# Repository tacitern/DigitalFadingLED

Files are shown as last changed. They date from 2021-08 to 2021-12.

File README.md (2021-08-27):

# DigitalFadingLED
Microcontroller project which uses a usb virtual serial port to control a RGB LEDs color, brightness and fade rate

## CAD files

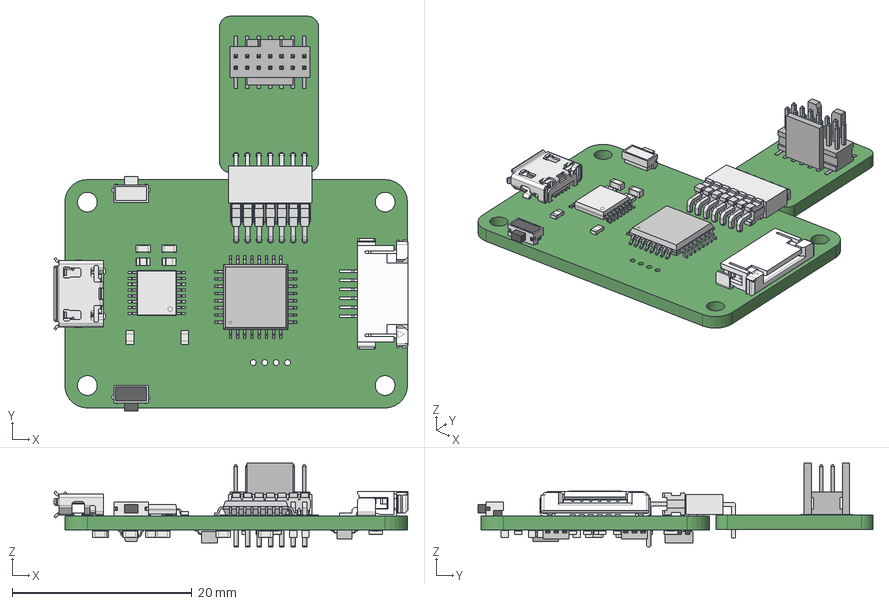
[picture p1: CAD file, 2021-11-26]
hardware/DigitalBoardandProgrammingBoard.FCStd
39.4 x 43.9 x 9.33 mm

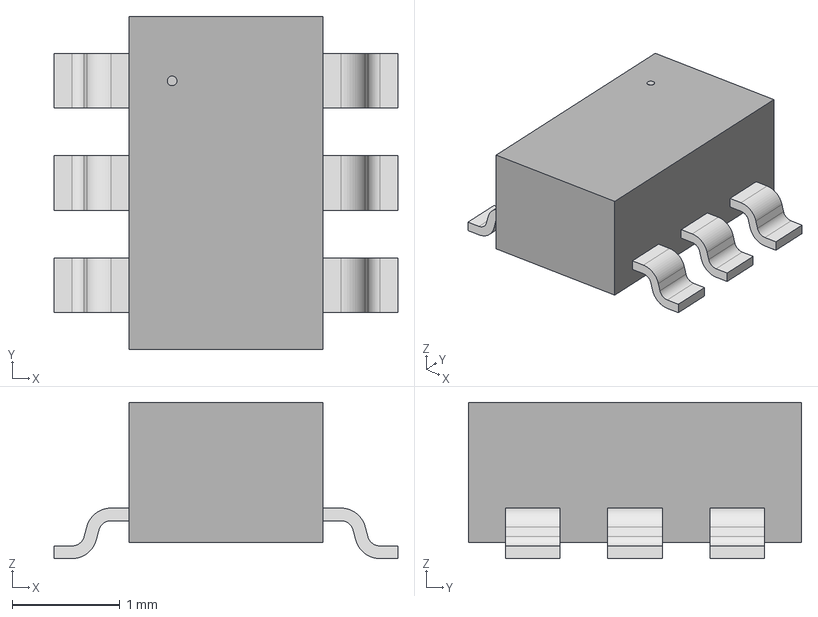
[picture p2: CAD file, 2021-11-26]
hardware/DigitalFadingLED/footprints/34AA02_EEPROM/SOT-23-6_MC_MCH.step
3.20 x 3.10 x 1.45 mm

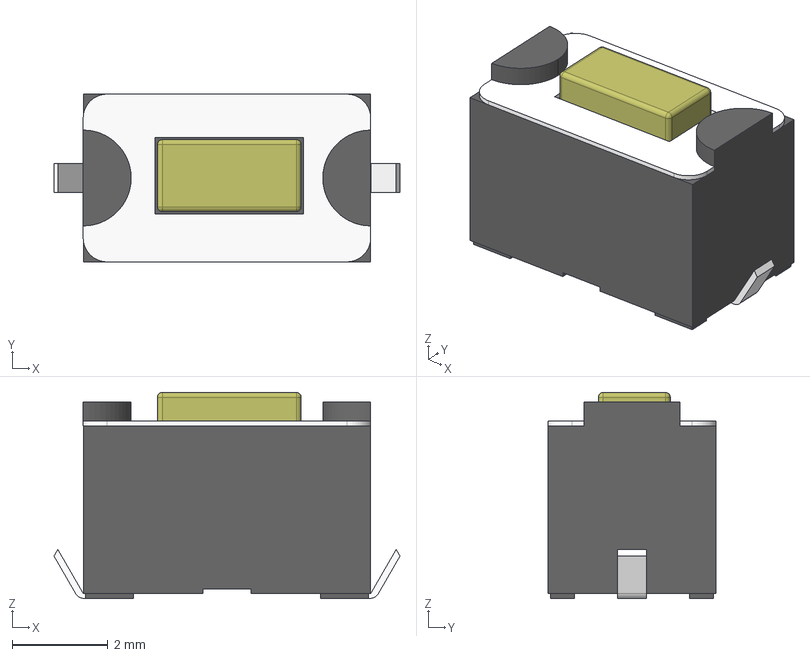
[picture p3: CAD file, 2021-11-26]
hardware/DigitalFadingLED/footprints/95C04A3GWRT_Button/95C04A3GWRT.step
7.22 x 3.50 x 4.30 mm

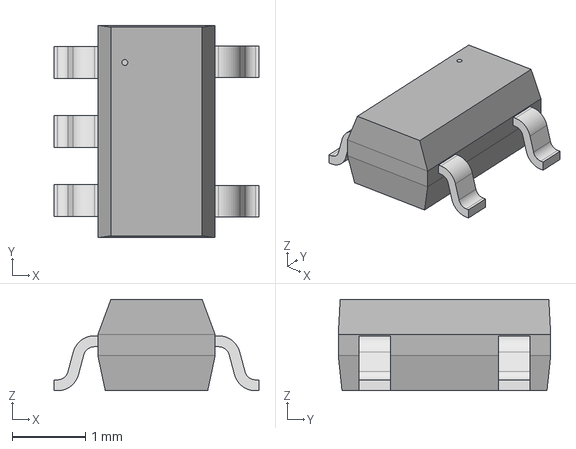
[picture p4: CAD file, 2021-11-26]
hardware/DigitalFadingLED/footprints/BU33SD5WG-TR_3V3_REG/SSOP5_ROM.step
2.79 x 2.90 x 1.25 mm

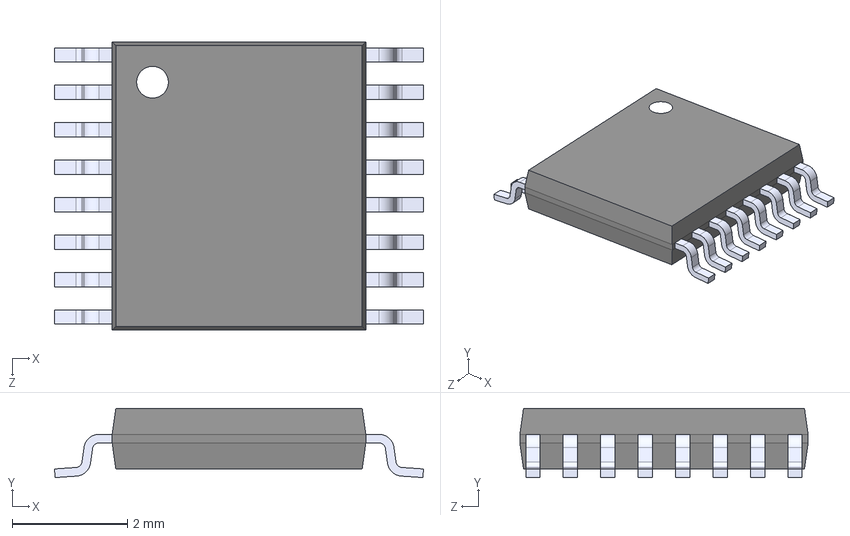
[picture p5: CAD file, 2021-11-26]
hardware/DigitalFadingLED/footprints/FT230XS/FX230.step
6.40 x 1.20 x 5.00 mm

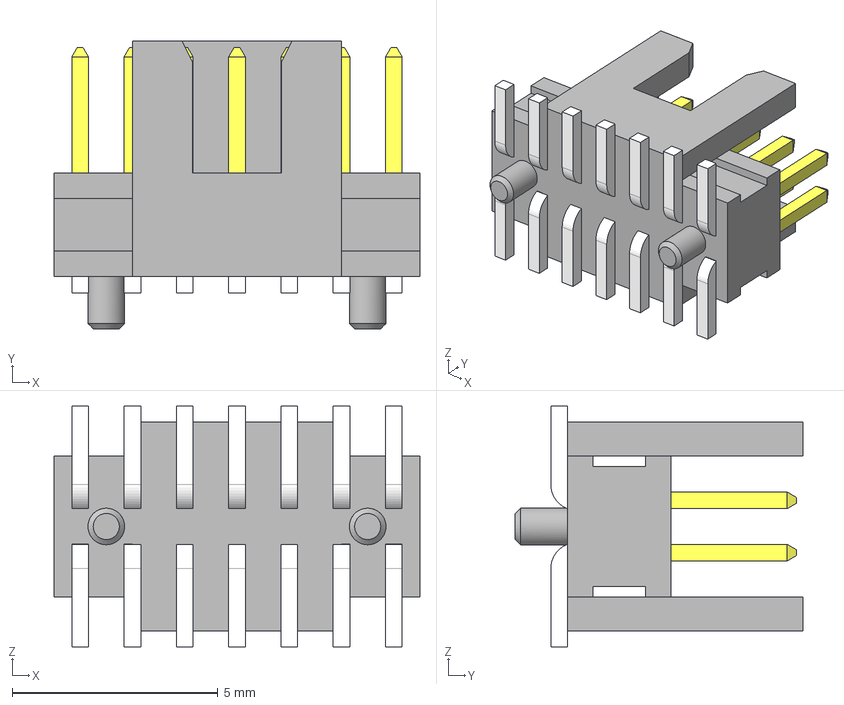
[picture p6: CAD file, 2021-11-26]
hardware/DigitalFadingLED/footprints/FTSH-107-01-L-DV-K-A_ProgrammingHeader/FTSH-107-01-L-DV-K-A.stp
8.89 x 6.98 x 5.84 mm
_FTSH-107-01-L-DV-K-A_body
_FTSH-107-01-L-DV-K-A_pins1
_FTSH-107-01-L-DV-K-A_pins2

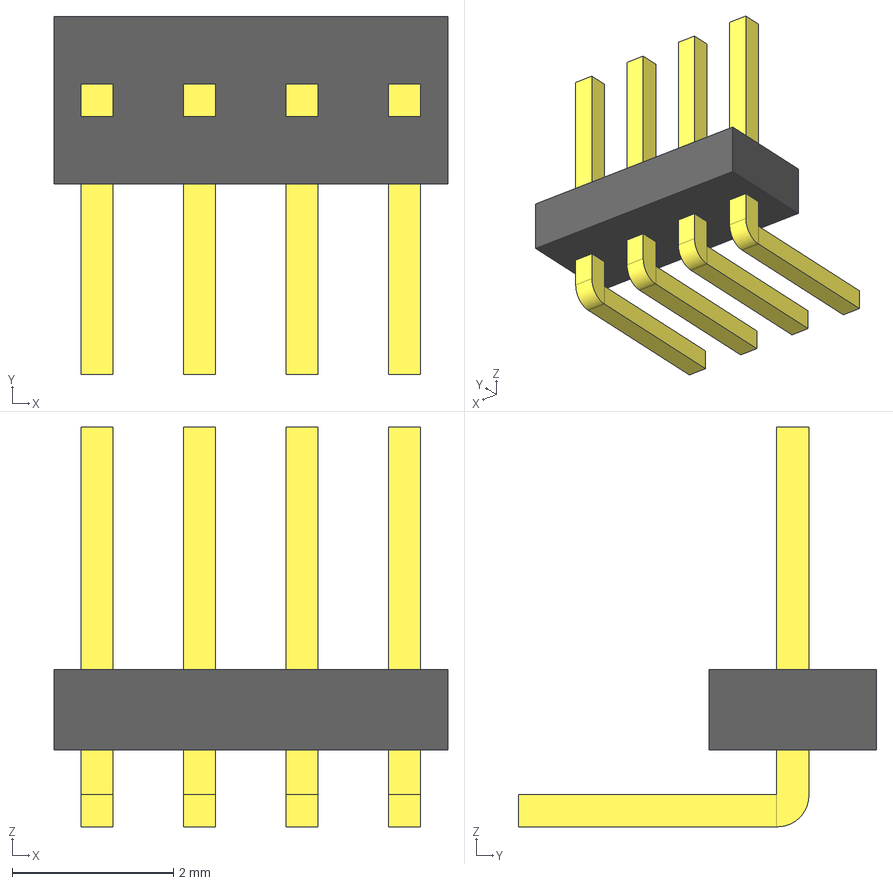
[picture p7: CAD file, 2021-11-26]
hardware/DigitalFadingLED/footprints/GRPB041VWCN-RC_4pos_PinHeader/GRPB041VWCN-RC.step
4.88 x 4.44 x 4.95 mm

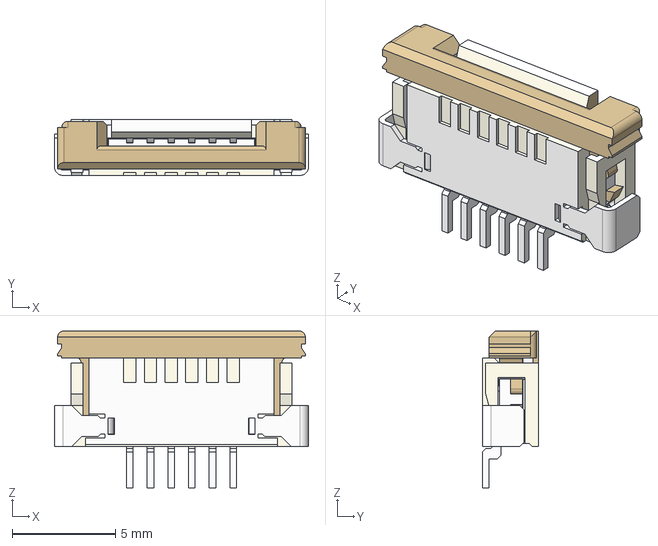
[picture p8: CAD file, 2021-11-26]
hardware/DigitalFadingLED/footprints/Molex_FFC/Molex_FFC_0522070633.step
12.3 x 2.70 x 7.60 mm

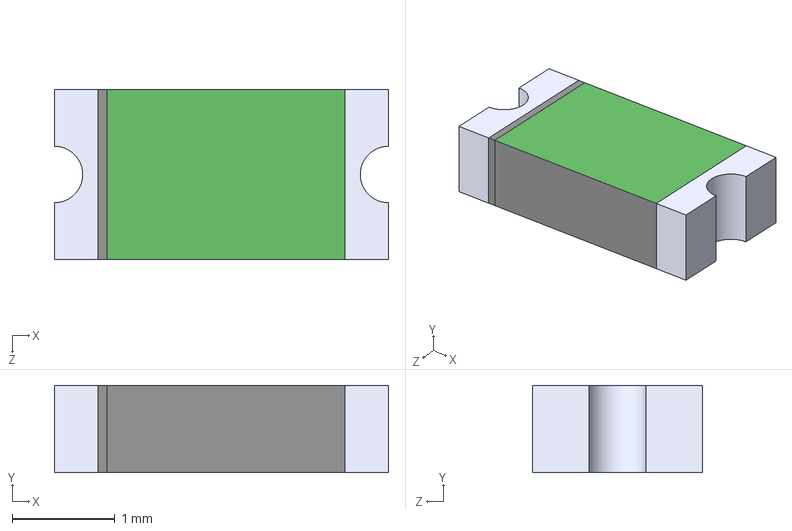
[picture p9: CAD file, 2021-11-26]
hardware/DigitalFadingLED/footprints/PTC_0ZCJ0020FF2E.STEP
3.25 x 0.85 x 1.65 mm

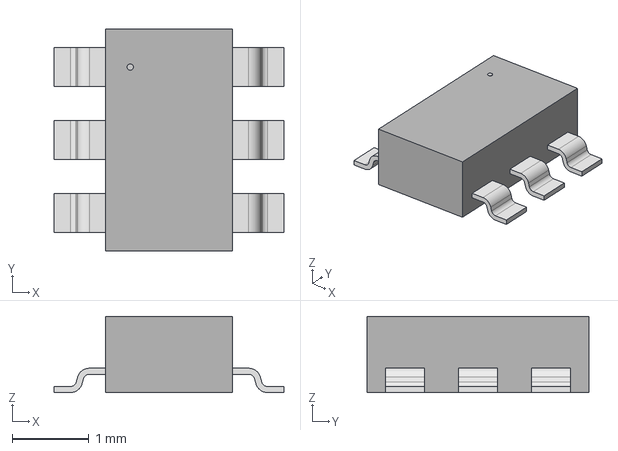
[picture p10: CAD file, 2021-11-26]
hardware/DigitalFadingLED/footprints/QS6K21_2-N-CH/TRANS_QS6_ROM.step
3.00 x 2.90 x 0.993 mm

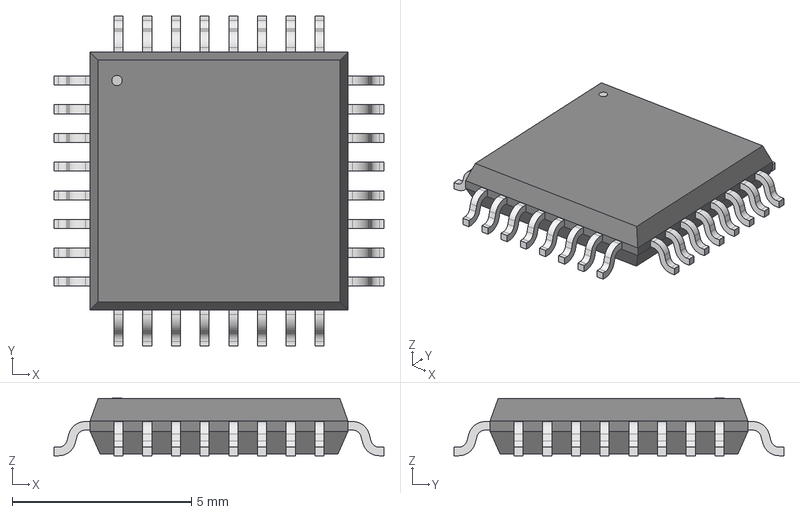
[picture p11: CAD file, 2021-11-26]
hardware/DigitalFadingLED/footprints/STM32L071KZT6/LQFP32_7X7X1P4.step
9.19 x 9.19 x 1.60 mm

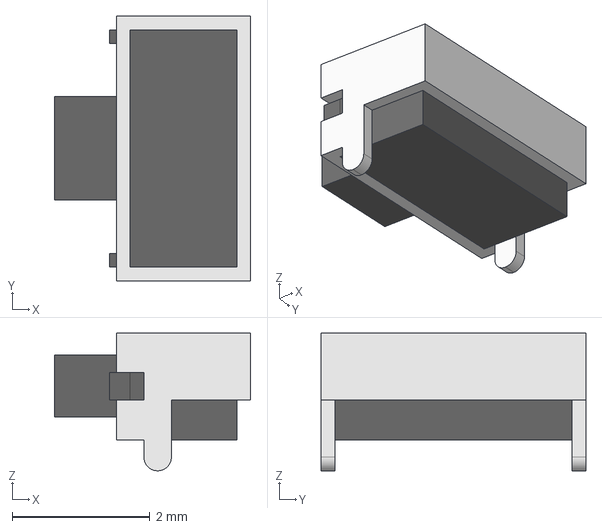
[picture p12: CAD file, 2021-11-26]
hardware/DigitalFadingLED/footprints/TL6340AF160Q_Button/TL6340AF160Q.step
2.85 x 3.85 x 2.00 mm

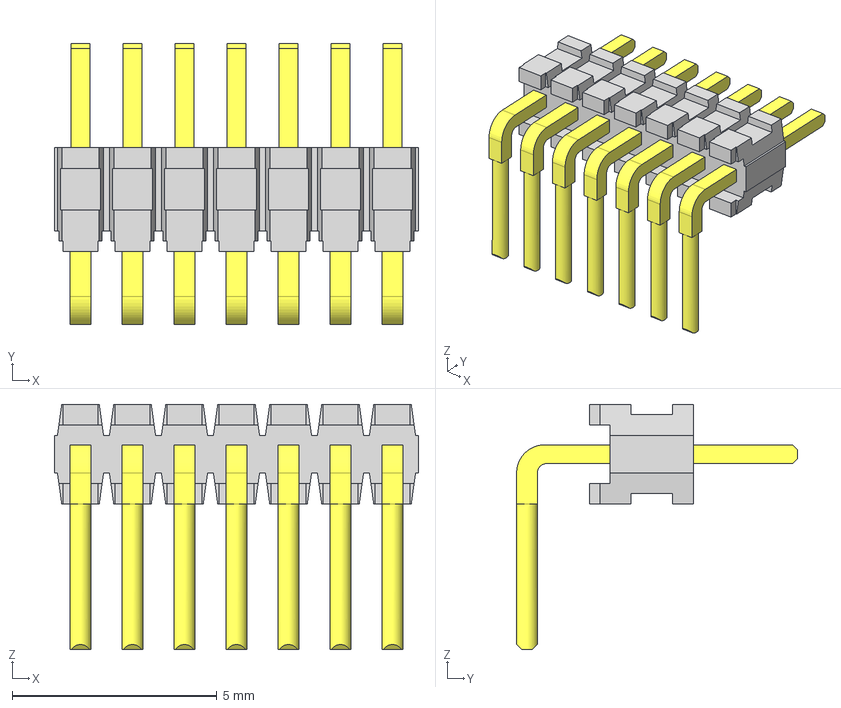
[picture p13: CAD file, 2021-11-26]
hardware/DigitalFadingLED/footprints/TMS-107-02-G-S-RA_7pos_PinHeader/TMS-107-02-G-S-RA.stp
8.89 x 6.86 x 5.99 mm
_TMS-107-S_header
_T-1M6-07-02-S-RA

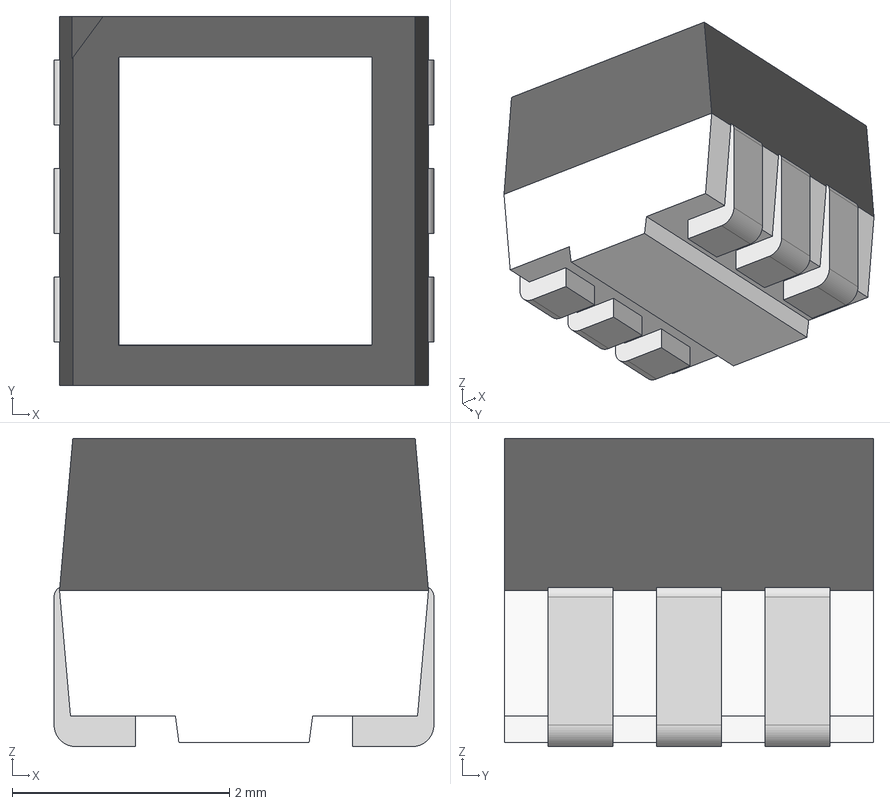
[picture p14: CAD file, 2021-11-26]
hardware/LedBoard/footprints/6-PLCC.STEP
3.50 x 3.40 x 2.84 mm

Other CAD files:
hardware/DigitalFadingLED/footprints/QS6M4_N-CH_P-CH/TRANS_QS6_ROM.step
hardware/LedBoard/LedBoard.step
hardware/DigitalFadingLED/footprints/95C04A3GWRT_Button/95C04A3GWRT.FCStd
hardware/DigitalFadingLED/footprints/FT230XS/FX230XS.FCStd
hardware/DigitalFadingLED/footprints/GRPB041VWCN-RC_4pos_PinHeader/GRPB041VWCN-RC.FCStd
hardware/DigitalFadingLED/footprints/Micro_USB_10118194-0001LF/10118194-0001LF.step
hardware/DigitalFadingLED/footprints/TL6340AF160Q_Button/TL6340AF160Q.FCStd
hardware/LedBoard/footprints/PLCC6.FCStd
hardware/ProgrammingAdapterBoard/ProgrammingAdapterBoard.step
hardware/ProgrammingAdapterBoard/footprints/Preci-Dip_851-87-007-20-001101_7pos_Soccket/851-87-007-20-001101.FCStd
hardware/ProgrammingAdapterBoard/footprints/Preci-Dip_851-87-007-20-001101_7pos_Soccket/851-87-007-20-001101.step

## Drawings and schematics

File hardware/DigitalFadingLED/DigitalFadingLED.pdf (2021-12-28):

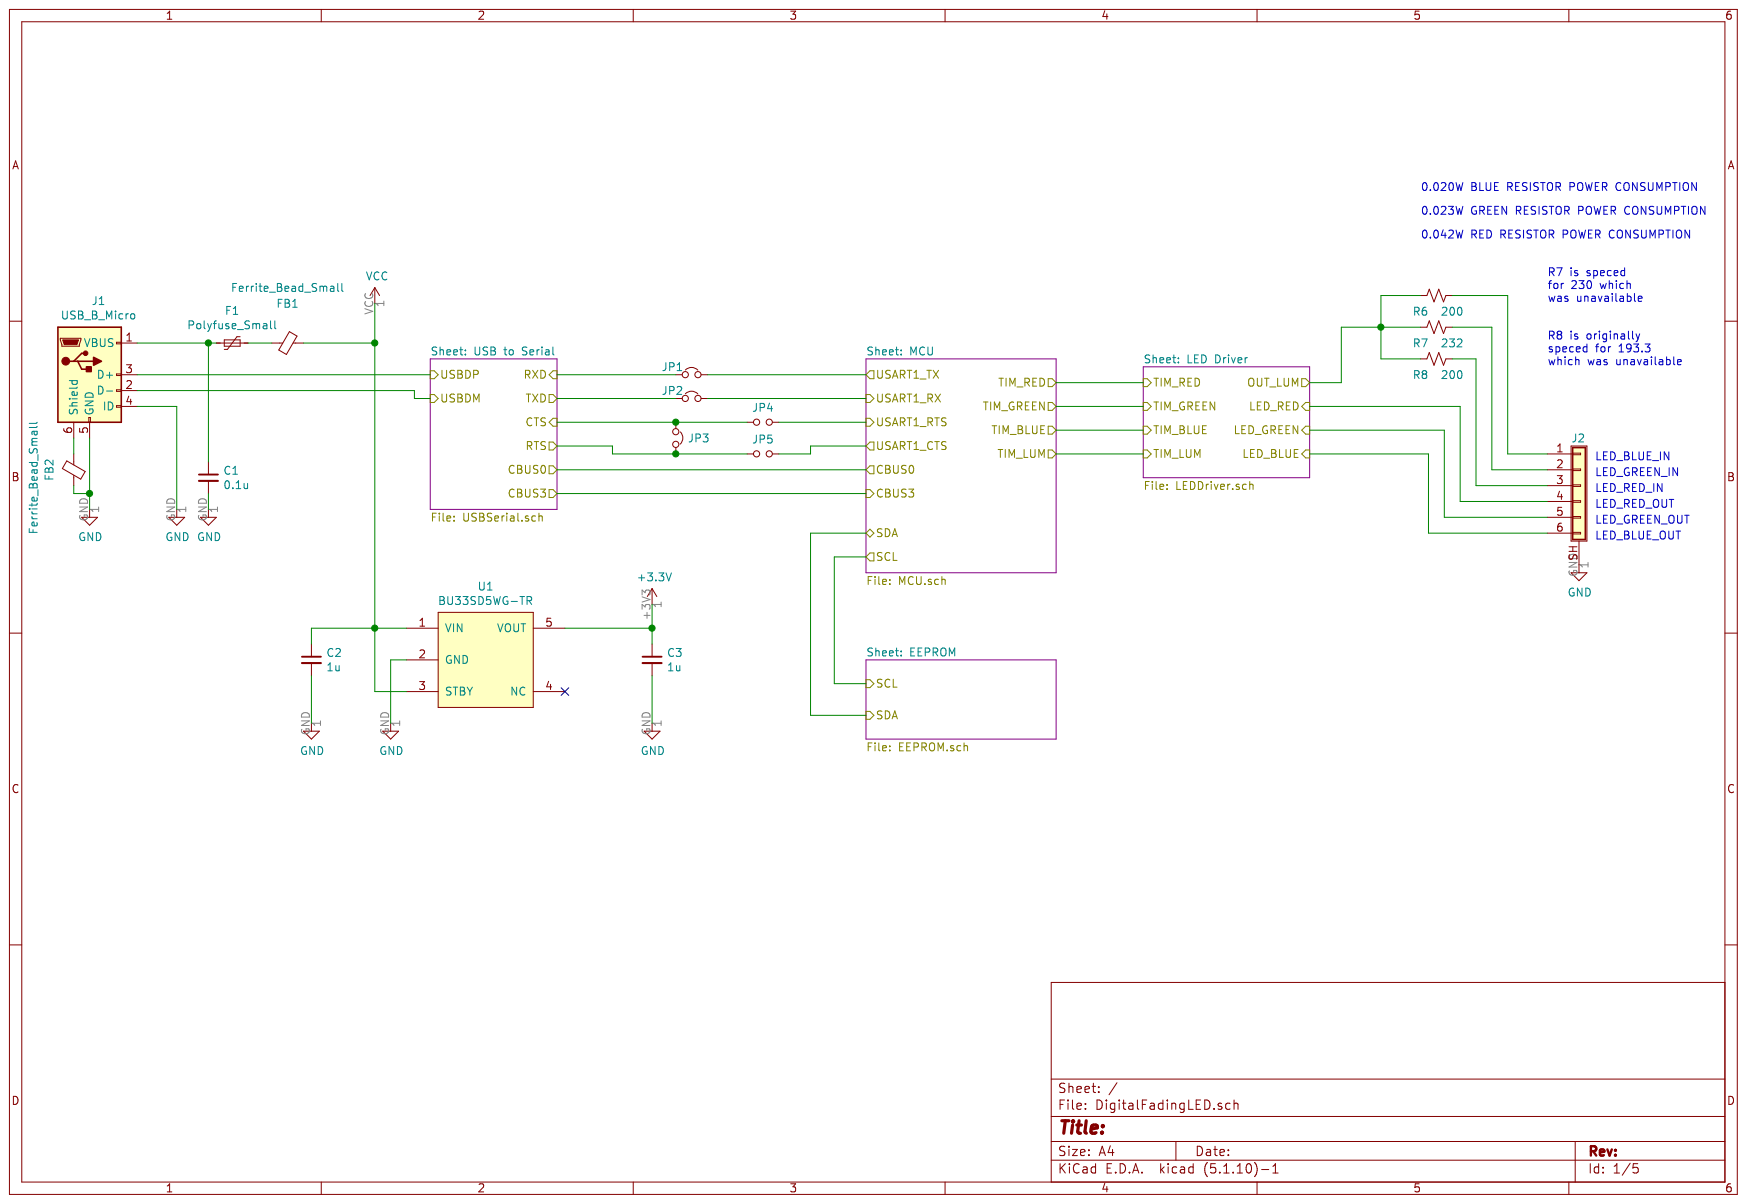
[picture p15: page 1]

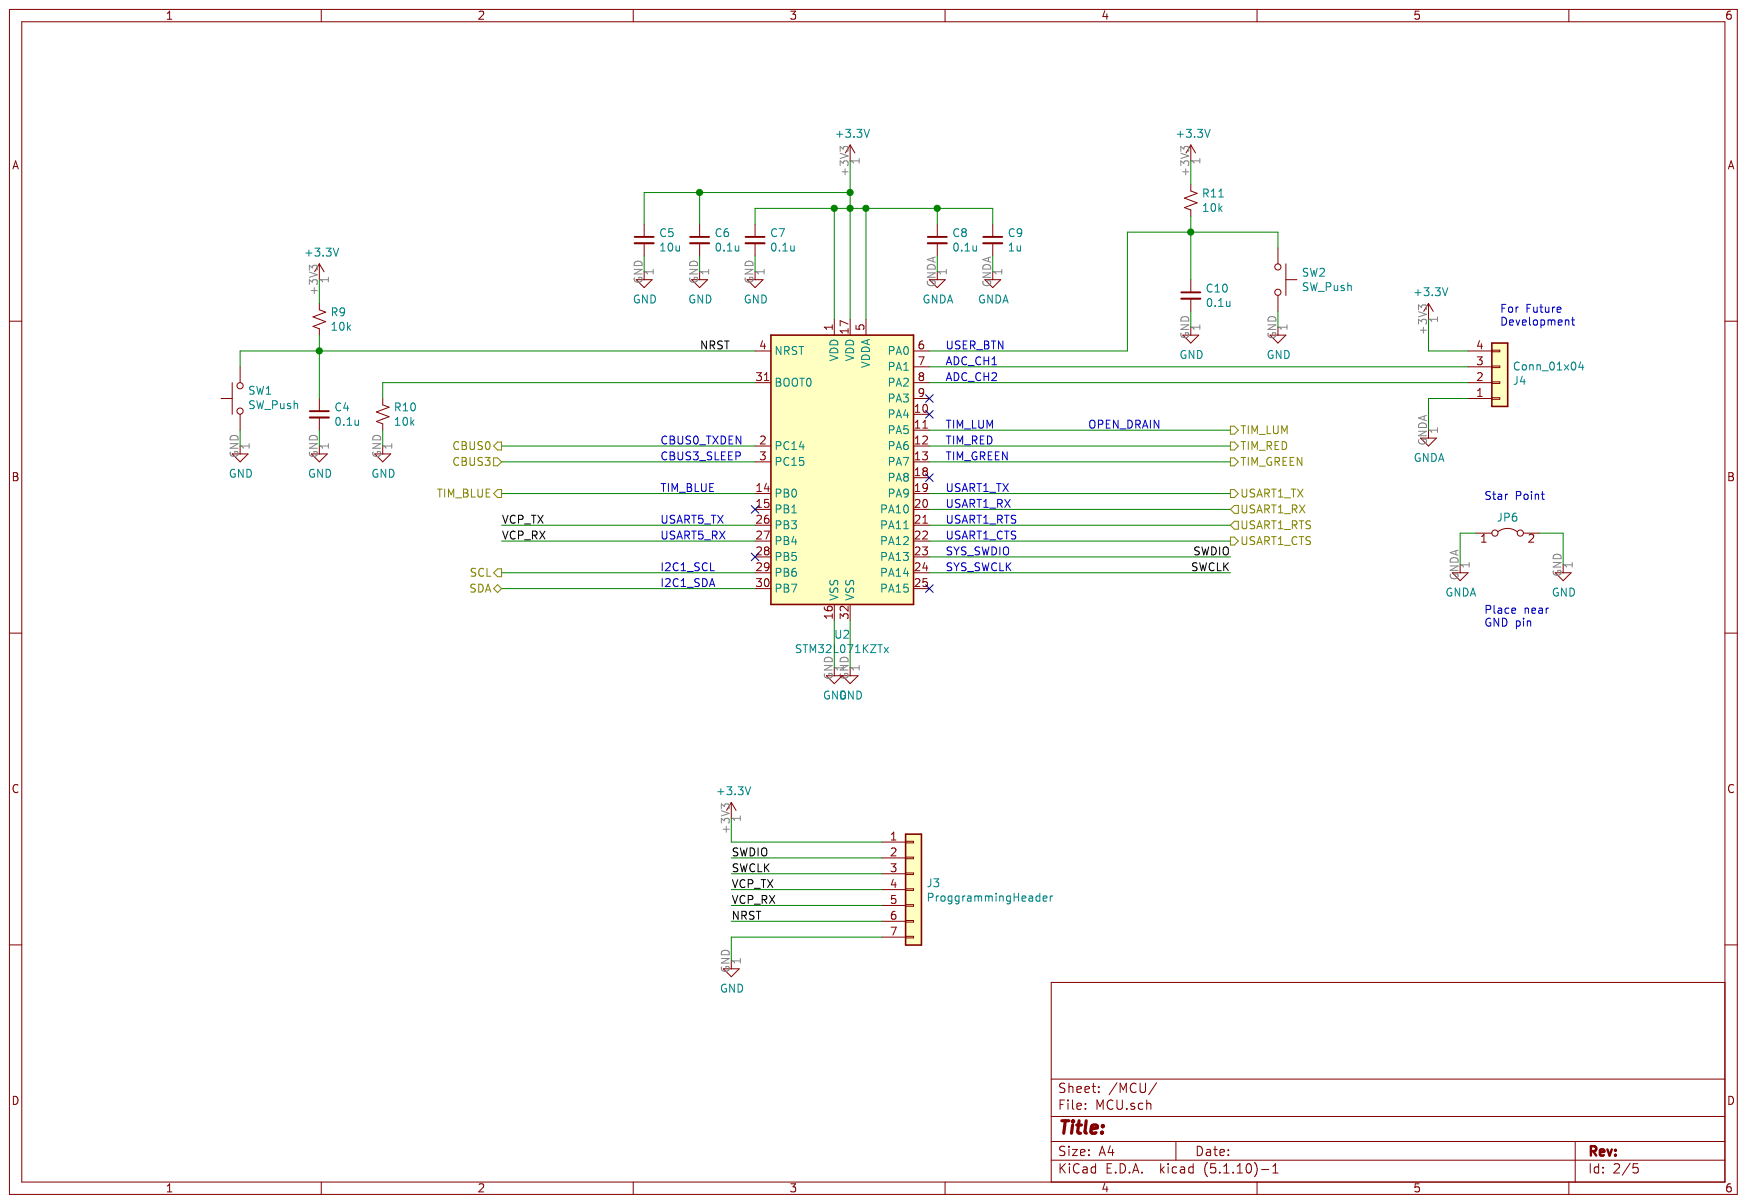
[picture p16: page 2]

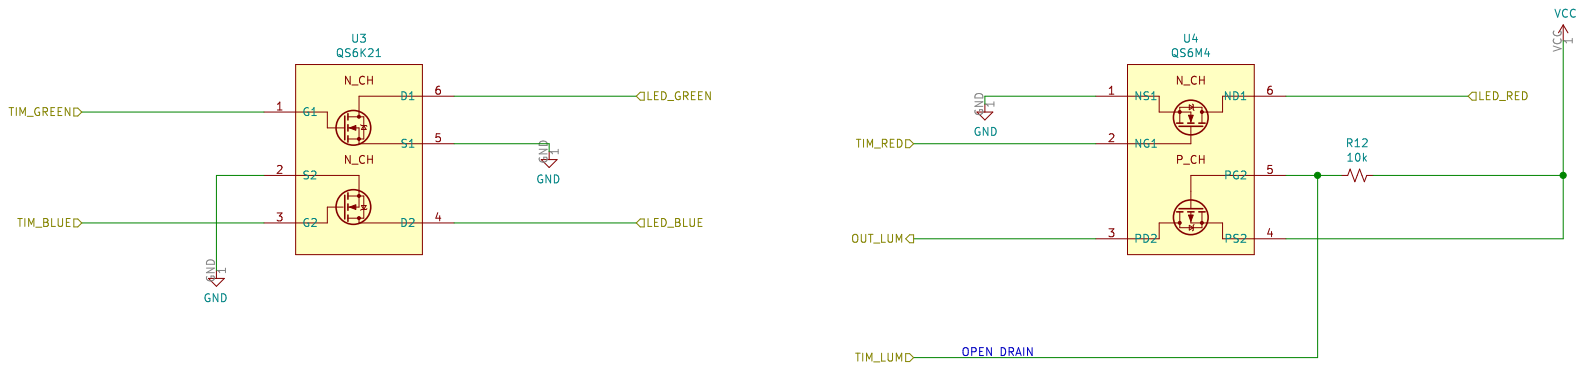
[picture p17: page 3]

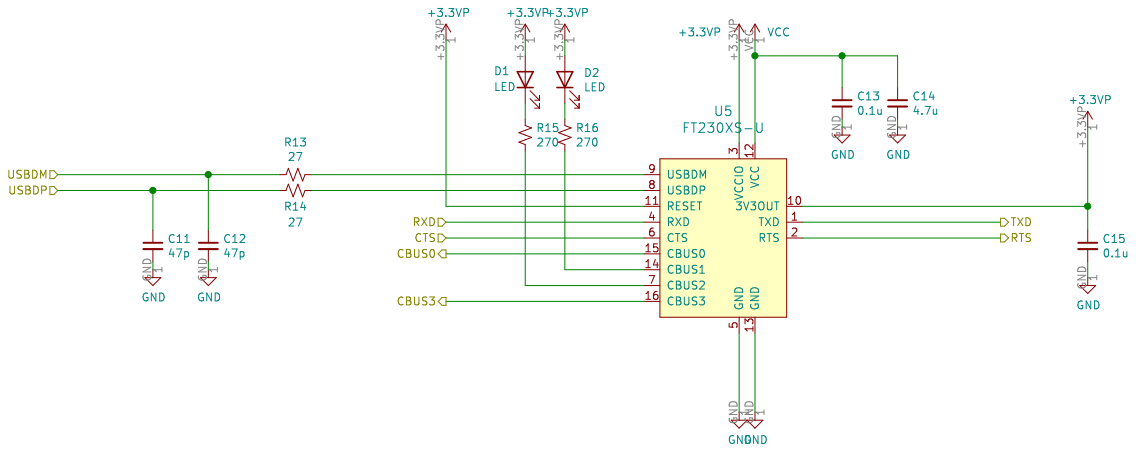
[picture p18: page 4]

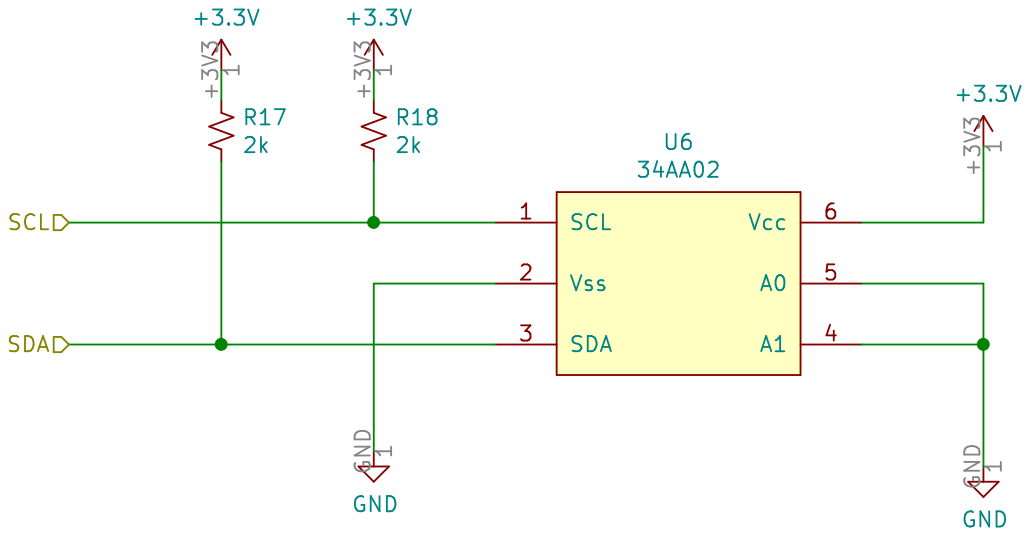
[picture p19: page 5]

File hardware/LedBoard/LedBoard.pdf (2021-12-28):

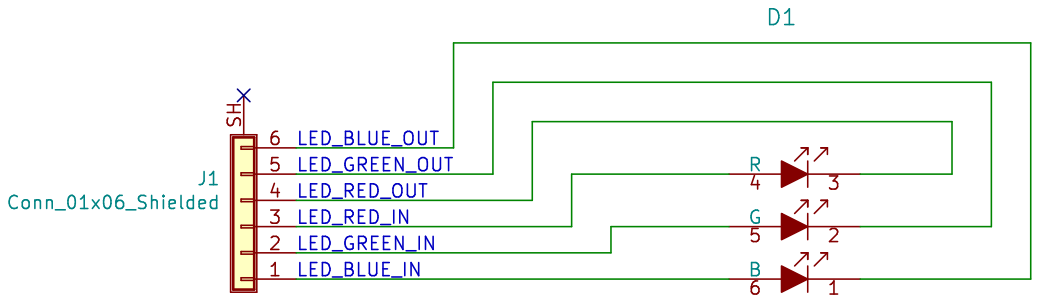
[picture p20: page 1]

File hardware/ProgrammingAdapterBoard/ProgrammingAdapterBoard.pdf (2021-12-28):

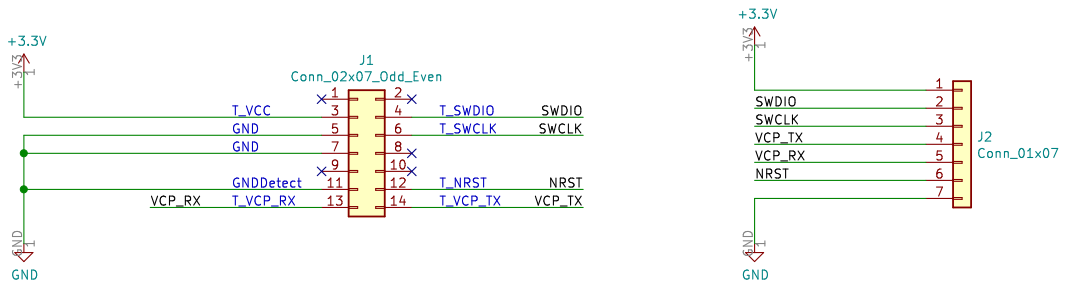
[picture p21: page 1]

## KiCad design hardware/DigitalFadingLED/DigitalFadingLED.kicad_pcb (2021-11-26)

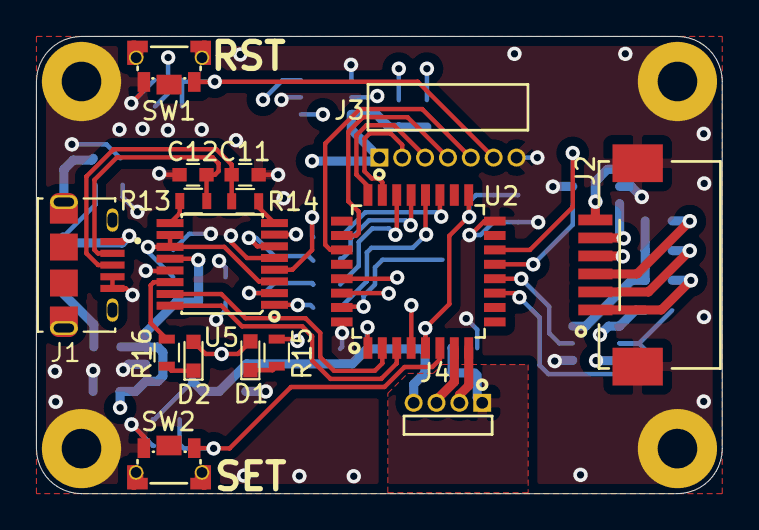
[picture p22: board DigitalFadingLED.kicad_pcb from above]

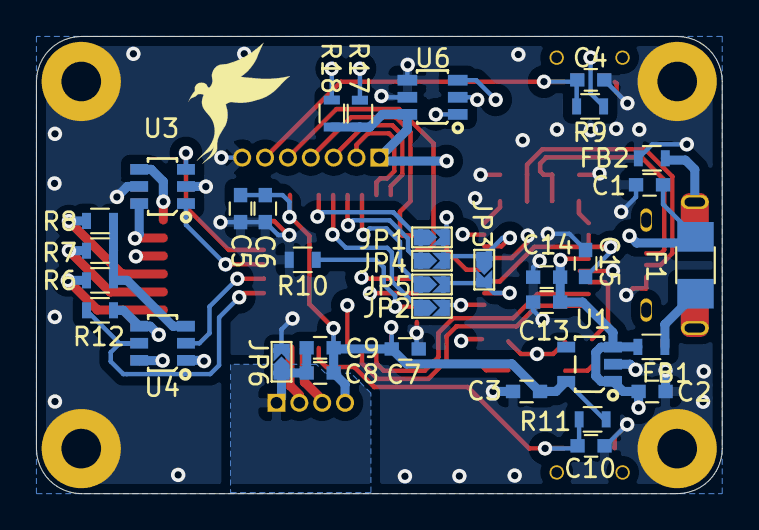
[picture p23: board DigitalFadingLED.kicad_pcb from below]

Board: 4 copper layers, 38.1 x 25.4 mm, 51 parts (35 on the bottom side), 47 nets.

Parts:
C1, C4, C6, C7, C8, C10, C13, C15: 0.1u; C_0603
C2, C3, C9: 1u; C_0603
C5: 10u; C_0603
C11, C12: 47p; C_0603
C14: 4.7u; C_0603
D1, D2: LED; LED_0603
F1: Polyfuse_Small; Fuse_SMD1206_Wave
FB1, FB2: Ferrite_Bead_Small; R_0603
J1: USB_B_Micro; AMPHENOL_10118194-0001LF
J2: molex_FFC_0522070633
J3: Conn_01x07; TMS-107-02-G-S-RA
J4: Conn_01x04; GRPB041VWCN-RC
JP1, JP2, JP3, JP4, JP5, JP6: jump
R6, R8: 200; R_0603
R7: 232; R_0603
R9, R10, R11, R12: 10k; R_0603
R13, R14: 27; R_0603
R15, R16: 270; R_0603
R17, R18: 2k; R_0603
SW1, SW2: SW_Push; TL6340AF160Q
U1: BU33SD5WG-TR; BU33SD5WG
U2: STM32L071KZTx; STM32L071KZT6
U3: QS6K21; QS6K21TR
U4: QS6M4; QS6K21TR
U5: FT230XS-U; FT230XS
U6: 34AA02

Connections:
+3.3VP: C15.1, D1.2, D2.2, U5.3, U5.10, U5.11
+3V3: C3.1, C5.1, C6.1, C7.1, C8.1, C9.1, J3.1, J4.4, R9.1, R11.1, R17.1, R18.1, U1.5, U2.1, U2.5, U2.17, U6.6
/EEPROM/SCL: R18.2, U2.29, U6.1
/EEPROM/SDA: R17.2, U2.30, U6.3
/LED Driver/LED_BLUE: J2.6, U3.4
/LED Driver/LED_GREEN: J2.5, U3.6
/LED Driver/LED_RED: J2.4, U4.6
/LED Driver/OUT_LUM: R6.2, R7.2, R8.2, U4.3
/LED Driver/TIM_BLUE: U2.14, U3.3
/LED Driver/TIM_GREEN: U2.13, U3.1
/LED Driver/TIM_LUM: R12.2, U2.11, U4.5
/LED Driver/TIM_RED: U2.12, U4.2
/MCU/CBUS0: U2.2, U5.15
/MCU/CBUS3: U2.3, U5.16
/MCU/NRST: C4.1, J3.6, R9.2, SW1.2, U2.4
/MCU/SWCLK: J3.3, U2.24
/MCU/SWDIO: J3.2, U2.23
/MCU/USART1_CTS: JP5.1, U2.22
/MCU/USART1_RTS: JP4.1, U2.21
/MCU/USART1_RX: JP2.1, U2.20
/MCU/USART1_TX: JP1.1, U2.19
/MCU/VCP_RX: J3.5, U2.27
/MCU/VCP_TX: J3.4, U2.26
/USB to Serial/CTS: JP3.1, JP4.2, U5.6
/USB to Serial/RTS: JP3.2, JP5.2, U5.2
/USB to Serial/RXD: JP1.2, U5.4
/USB to Serial/TXD: JP2.2, U5.1
/USB to Serial/USBDM: C12.1, J1.2, R13.2
/USB to Serial/USBDP: C11.1, J1.3, R14.2
GND: C1.2, C2.2, C3.2, C4.2, C5.2, C6.2, C7.2, C10.2, C11.2, C12.2, C13.2, C14.2, C15.2, FB2.1, J1.4, J1.5, J2.S, J3.7, JP6.2, R10.2, SW1.1, SW2.2, U1.2, U2.16, U2.32, U3.2, U3.5, U4.1, U5.5, U5.13, U6.2, U6.4, U6.5
GNDA: C8.2, C9.2, J4.1, JP6.1
unnamed: C1.1, F1.2, J1.1
unnamed: C10.1, R11.2, SW2.1, U2.6
unnamed: D1.1, R15.1
unnamed: D2.1, R16.1
unnamed: F1.1, FB1.2
unnamed: J2.1, R6.1
unnamed: J2.2, R7.1
unnamed: J2.3, R8.1
unnamed: J4.2, U2.8
unnamed: J4.3, U2.7
unnamed: R10.1, U2.31
unnamed: R13.1, U5.9
unnamed: R14.1, U5.8
unnamed: R15.2, U5.7
unnamed: R16.2, U5.14
VCC: C2.1, C13.1, C14.1, FB1.1, R12.1, U1.1, U1.3, U4.4, U5.12

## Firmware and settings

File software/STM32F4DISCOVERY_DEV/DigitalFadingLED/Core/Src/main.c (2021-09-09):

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
/* Includes ------------------------------------------------------------------*/
#include "main.h"
#include "i2c.h"
#include "tim.h"
#include "usart.h"
#include "gpio.h"

/* USER CODE BEGIN Includes */
#include "serial_shell.h"
#include "34AA02_EEPROM.h"
/* USER CODE END Includes */


/* USER CODE BEGIN PV */
uint8_t buf[1];
uint8_t len = sizeof(buf);
/* USER CODE END PV */

void SystemClock_Config(void);
/**
  * @brief  The application entry point.
  * @retval int
  */
int main(void)
{
  /* MCU Configuration--------------------------------------------------------*/

  /* Reset of all peripherals, Initializes the Flash interface and the Systick. */
  HAL_Init();

  /* Configure the system clock */
  SystemClock_Config();

  /* Initialize all configured peripherals */
  MX_GPIO_Init();
  MX_TIM3_Init();
  MX_TIM4_Init();
  MX_TIM7_Init();
  MX_USART3_UART_Init();
  MX_I2C1_Init();
  /* USER CODE BEGIN 2 */

  //Start uart rx interrupt
  HAL_UART_Receive_IT(&huart3, buf, len);

  //Start Color channels
  HAL_TIM_PWM_Start(&htim4, TIM_CHANNEL_1);
  HAL_TIM_PWM_Start(&htim4, TIM_CHANNEL_2);
  HAL_TIM_PWM_Start(&htim4, TIM_CHANNEL_3);

  //Start luminance channel
  HAL_TIM_PWM_Start(&htim3, TIM_CHANNEL_1);

  //Start luminance fade value update timer
  HAL_TIM_Base_Start_IT(&htim7);

  //Get Saved state from EEPROM
  uint16_t buf[6] = {0};
  readSavedData(buf, EEPROMADDRESS);

  //setID(buf[0])
  uint8_t startcolors[3] = {(uint8_t)buf[1], (uint8_t)buf[2], (uint8_t)buf[3]};
  SetColorValues(startcolors);
  SetLuminanceValue(buf[4]);
  SetRateValue(buf[5]);

  /* USER CODE END 2 */

  /* Infinite loop */
  /* USER CODE BEGIN WHILE */
  while (1)
  {
      CheckCommand();
      ProcessLuminance();
    /* USER CODE END WHILE */

    /* USER CODE BEGIN 3 */
  }
  /* USER CODE END 3 */
}

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
/* USER CODE BEGIN 4 */
void HAL_UART_RxCpltCallback(UART_HandleTypeDef *huart){
  ProcessSerial(buf);
  HAL_UART_Receive_IT(&huart3, buf, len);
}
/* USER CODE END 4 */
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


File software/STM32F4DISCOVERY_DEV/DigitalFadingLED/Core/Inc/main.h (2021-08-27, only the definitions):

#define CS_I2C_SPI_Pin GPIO_PIN_3
#define CS_I2C_SPI_GPIO_Port GPIOE
#define PC14_OSC32_IN_Pin GPIO_PIN_14
#define PC14_OSC32_IN_GPIO_Port GPIOC
#define PC15_OSC32_OUT_Pin GPIO_PIN_15
#define PC15_OSC32_OUT_GPIO_Port GPIOC
#define PH0_OSC_IN_Pin GPIO_PIN_0
#define PH0_OSC_IN_GPIO_Port GPIOH
#define PH1_OSC_OUT_Pin GPIO_PIN_1
#define PH1_OSC_OUT_GPIO_Port GPIOH
#define OTG_FS_PowerSwitchOn_Pin GPIO_PIN_0
#define OTG_FS_PowerSwitchOn_GPIO_Port GPIOC
#define PDM_OUT_Pin GPIO_PIN_3
#define PDM_OUT_GPIO_Port GPIOC
#define B1_Pin GPIO_PIN_0
#define B1_GPIO_Port GPIOA
#define I2S3_WS_Pin GPIO_PIN_4
#define I2S3_WS_GPIO_Port GPIOA
#define SPI1_SCK_Pin GPIO_PIN_5
#define SPI1_SCK_GPIO_Port GPIOA
#define SPI1_MISO_Pin GPIO_PIN_6
#define SPI1_MISO_GPIO_Port GPIOA
#define SPI1_MOSI_Pin GPIO_PIN_7
#define SPI1_MOSI_GPIO_Port GPIOA
#define BOOT1_Pin GPIO_PIN_2
#define BOOT1_GPIO_Port GPIOB
#define CLK_IN_Pin GPIO_PIN_10
#define CLK_IN_GPIO_Port GPIOB
#define I2S3_MCK_Pin GPIO_PIN_7
#define I2S3_MCK_GPIO_Port GPIOC
#define VBUS_FS_Pin GPIO_PIN_9
#define VBUS_FS_GPIO_Port GPIOA
#define OTG_FS_ID_Pin GPIO_PIN_10
#define OTG_FS_ID_GPIO_Port GPIOA
#define OTG_FS_DM_Pin GPIO_PIN_11
#define OTG_FS_DM_GPIO_Port GPIOA
#define OTG_FS_DP_Pin GPIO_PIN_12
#define OTG_FS_DP_GPIO_Port GPIOA
#define SWDIO_Pin GPIO_PIN_13
#define SWDIO_GPIO_Port GPIOA
#define SWCLK_Pin GPIO_PIN_14
#define SWCLK_GPIO_Port GPIOA
#define I2S3_SCK_Pin GPIO_PIN_10
#define I2S3_SCK_GPIO_Port GPIOC
#define I2S3_SD_Pin GPIO_PIN_12
#define I2S3_SD_GPIO_Port GPIOC
#define Audio_RST_Pin GPIO_PIN_4
#define Audio_RST_GPIO_Port GPIOD
#define OTG_FS_OverCurrent_Pin GPIO_PIN_5
#define OTG_FS_OverCurrent_GPIO_Port GPIOD
#define SWO_Pin GPIO_PIN_3
#define SWO_GPIO_Port GPIOB
#define MEMS_INT2_Pin GPIO_PIN_1
#define MEMS_INT2_GPIO_Port GPIOE

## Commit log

2021-08-27 Code is still in work, this is an initial functioning commit
    [DigitalFadingLED Debug.cfg]
2021-09-01 Added 'SAVE?' serial shell command
    Added the command 'SAVE?'. This command list the current contents of the
    EEPROM.
2021-09-01 Added 'SAVE' command to Serial Shell
    'SAVE' command writes the current color, luminence and rate settings to
    thier respective EEPROM memory locations
2021-09-01 Added 'ID' command to the serial shell
    'ID' followed by an 8bit number sent through serial communication with
    the device allows the user to modify the device ID
2021-09-09 Added software folder
    Moved code into software folder
    [DigitalFadingLED Debug.cfg]
2021-09-09 Added underscore to stm32f4discovery dev code folder
    [DigitalFadingLED Debug.cfg]
2021-09-09 Initial hardware commit
    [DigitalFadingLED.kicad_pcb, DigitalFadingLED.sch]
2021-11-26 Added final V1 pcbs
    Added various component files
    Added kicad files and gerbers for LED board, Digital Board, and
    proggramming adpter boards
    [10118194-0001LF.step, 6-PLCC.STEP, 851-87-007-20-001101.FCStd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]
2021-12-28 Added pdfs for board schematics
2022-04-12 First cut command line util

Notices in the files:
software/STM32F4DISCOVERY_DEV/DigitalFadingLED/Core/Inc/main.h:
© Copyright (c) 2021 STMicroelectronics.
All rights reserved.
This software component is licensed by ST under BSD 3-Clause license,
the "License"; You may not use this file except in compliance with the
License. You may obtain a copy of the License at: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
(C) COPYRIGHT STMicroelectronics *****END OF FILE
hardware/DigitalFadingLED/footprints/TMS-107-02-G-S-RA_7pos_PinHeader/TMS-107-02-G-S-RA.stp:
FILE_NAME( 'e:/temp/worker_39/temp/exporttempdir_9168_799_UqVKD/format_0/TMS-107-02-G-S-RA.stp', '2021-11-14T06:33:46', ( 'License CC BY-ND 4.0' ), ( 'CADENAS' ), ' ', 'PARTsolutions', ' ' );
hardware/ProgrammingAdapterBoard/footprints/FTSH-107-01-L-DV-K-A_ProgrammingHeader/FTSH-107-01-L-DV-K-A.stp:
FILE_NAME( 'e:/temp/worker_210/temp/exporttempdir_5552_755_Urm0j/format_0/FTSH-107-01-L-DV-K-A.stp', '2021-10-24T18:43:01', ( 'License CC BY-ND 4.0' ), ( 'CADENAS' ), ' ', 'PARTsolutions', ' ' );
